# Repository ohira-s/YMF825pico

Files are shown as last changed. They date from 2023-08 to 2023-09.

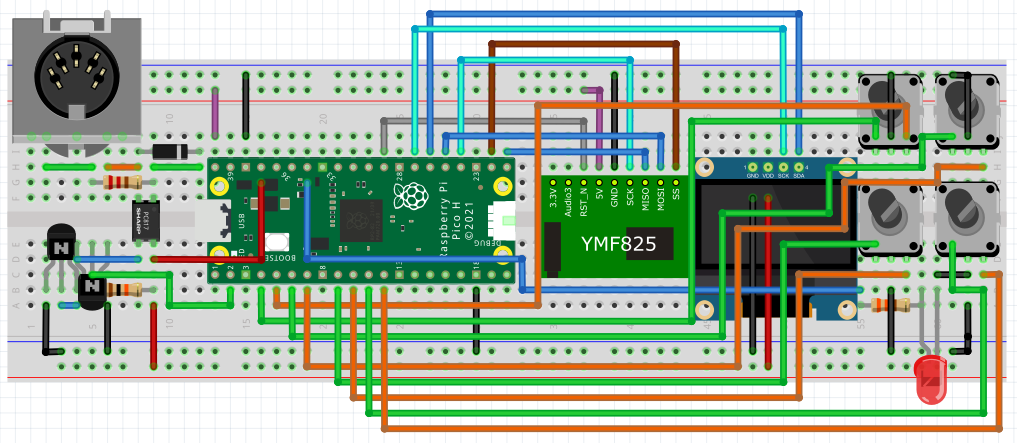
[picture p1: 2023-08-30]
doc/YMF825pico_bread.png

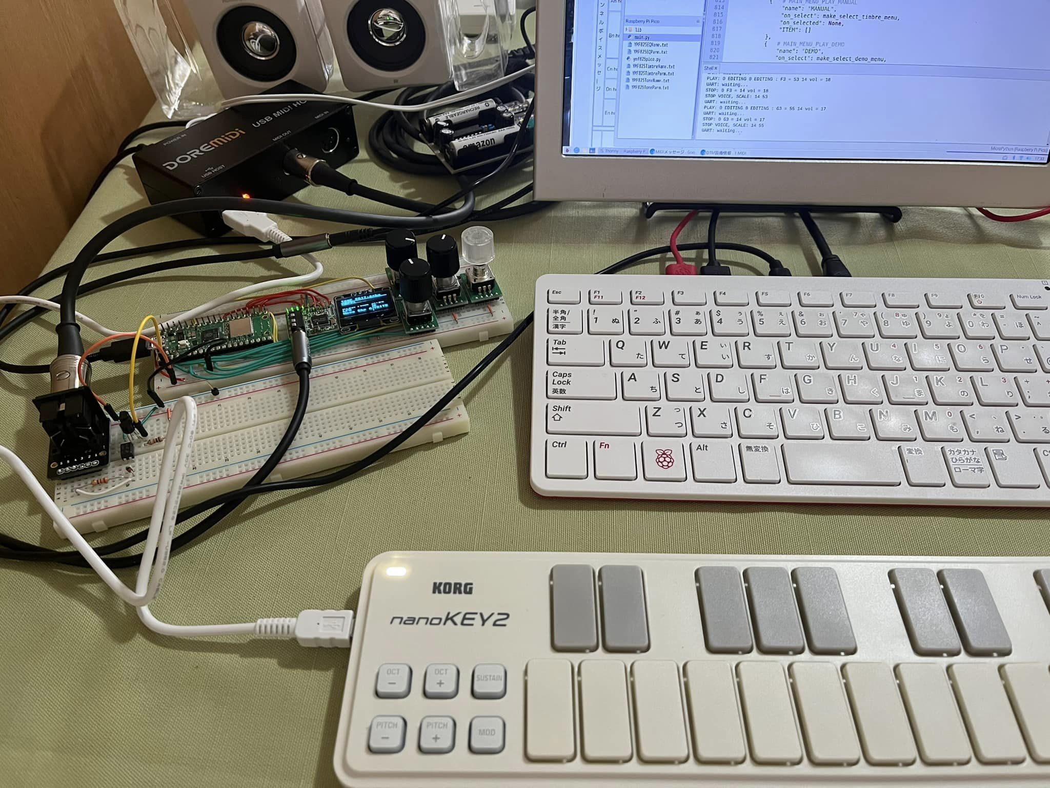
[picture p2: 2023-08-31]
doc/YMF825pico_photo.jpg

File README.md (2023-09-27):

# YMF825pico
YMF825 FM synthesizer controlled with Raspberry Pi PICO.

## Installations:
- Prepare Raspberry Pi PICO or PICO W with micropython.
- Copy all files in data folder into PICO / folder.
- Copy all files in scores folder into PICO /scores/ folder.
- Copy YMF825pico_synth_main.py into PICO as main.py.
- Copy YMF825pico.py into PICO.
- YMF825piBasic.py is a test program, so don't care this file.

## Quick start:
- Connect a MIDI OUT of your MIDI instrument to a MIDI DIN5 connector of YMF825pico.
- MIDI CH should be 1ch.
- Connect a passive speaker or amplifire to a audio output of YMF825 board.
- Turn on PICO.
- Play your MIDI instrument.

## Specifications:
- FM synthesizer with 7 algorithms and 4 operators (A, B, C, D).
- 29 wave forms each operator.
- 16 voices.  Each voice can have different tone.
- Multi Timbre. A timbre consists of 4 portions (0..3) with each tone.
- Each portion in a timbre has a MIDI channel to play with both note on and off.
- 3 layers biquad filters are placed following the sound output. 
- You can save 10 databanks each bank contains 20 Timbre sets, 20 Tones and 10 Equalizers in PICO.

## MIDI Events
- Note on event with verosity.
- Sustain pedal event.
- Pitch+ event increments the Base Tone Number (BTN).
- Pitch- event decrements the Base Tone Number (BTN).
- Modulation event resets the BTN to zero (default).
    Therefore ((MIDI CH - 1 + BTN) % 4) corresponds to a portion number to play.
    YMF825 chip does not support both pitch bend and modulation,
    so YMF825pico assigns the original functions to these events.

## Interfaces
- An OLED display and 4 rotary encoders for UI to control the synthesizer. 
- MIDI IN (DIN5) available (NOT support USB MIDI).
- Audio output for a stereo passive speaker (but output is monoral).
    
## YMF825 Sound Editor:
- [User's Manual](https://github.com/ohira-s/YMF825pico/blob/master/doc/YMF825picoUsersManual.md)
- [Web Site（日本語）](https://www.thymes-square.net/?p=41)

  The web site is written in Japanese, and access to the site might be limited from Japan for security problems.  Sorry for inconvenience.

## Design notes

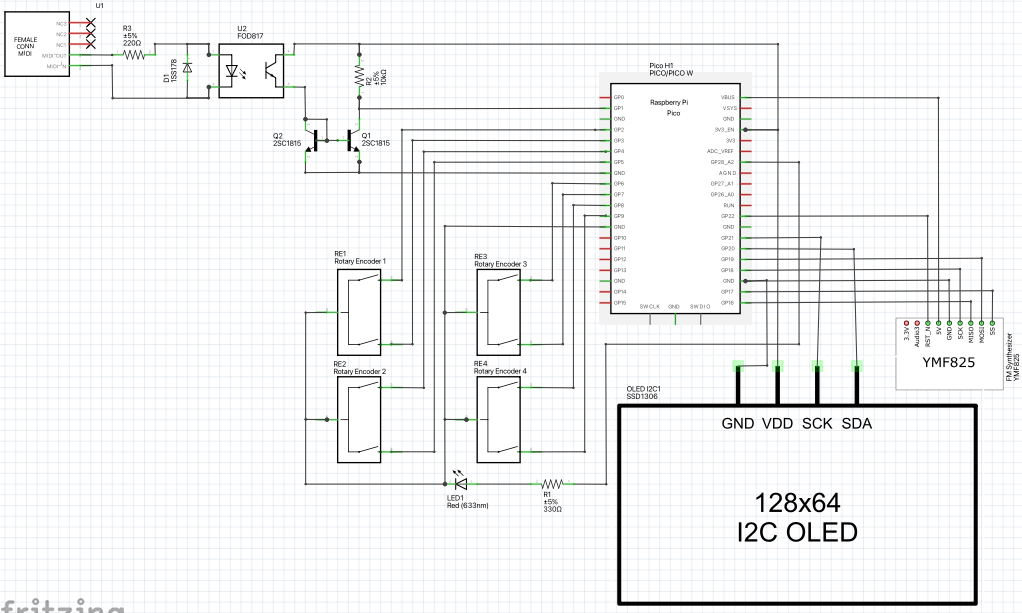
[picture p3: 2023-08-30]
doc/YMF825pico_circuit.png

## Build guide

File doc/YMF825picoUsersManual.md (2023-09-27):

# **YMF825pico User's Manual**
## Sound
- FM synthesizer with 7 algorithms and 4 operators (A, B, C, D).
- 29 wave forms each operator.
- 16 voices.  Each voice can have different tone.
- Multi Timbre. A timbre consists of 4 portions (0..3) with each tone.
- Each portion in a timbre has a MIDI channel to play with both note on and off.
- 3 layers biquad filters are placed following the sound output. 
- You can save 10 databanks each bank contains 20 Timbre sets, 20 Tones and 10 Equalizers in PICO.

    MIDI CHa ---> TIMBREx-PORTION0 ---> DATABANK0..9:TONE0..19 ---> VOICES0..15 / VOLUME0..31

    MIDI CHb ---> TIMBREx-PORTION1 ---> DATABANK0..9:TONE0..19 ---> VOICES0..15 / VOLUME0..31

    MIDI CHc ---> TIMBREx-PORTION2 ---> DATABANK0..9:TONE0..19 ---> VOICES0..15 / VOLUME0..31

    MIDI CHd ---> TIMBREx-PORTION3 ---> DATABANK0..9:TONE0..19 ---> VOICES0..15 / VOLUME0..31

| BLOCK: | DATABANK  | TIMBRE  | PORTION  | MIDI CH | VOICE | DATABANK:TONE  | EQUALIZER  |
|--- | --- | --- | --- | --- | --- | ----- | --- |
| QTY: | 0..9 | 0..19 | 0..3 | 1..16 | 0..15 | 0..19 | 0..9 |
| STRUCTURE: | DATABANKi | TIMBREj | PORTION0 | a  | V0from..V0to | DATABANKt:TONEp | EQUALIZERx |
| | | | PORTION1 | b | V1from..V1to | DATABANKu:TONEq | |
| | | | PORTION2 | c | V2from..V2to | DATABANKv:TONEr | |
| | | | PORTION3 | d | V3from..V3to | DATABANKw:TONEs | |

- You can assign same MIDI channel to any timbre potion.  In this case, all tones with the same MIDI channel will be played at the same time.

## MIDI Controles
- Note on event with MIDI channel and verosity.
- Note off event with MIDI channel.
- Sustain event pedal.
- Pitch+ event increments the Base Tone Number (BTN).
- Pitch- event decrements the Base Tone Number (BTN).
- Modulation event resets the BTN to zero (default).

  Therefore (MIDI Channel + BTN + 1) % 4 corresponds to a portion number to play. YMF825 chip does not support both pitch bend and modulation, so YMF825pico assigns the original functions to these events.

## Interfaces
- An OLED display and 4 rotary encoders for UI to control the synthesizer.
- MIDI IN (DIN5) available (NOT support USB MIDI).
- Audio output for a stereo passive speaker (but output is monoral).
## Softwares
- Interpreter: micropython for Raspberry Pi PICO.
- Application: main.py and ymf825pico.py
## Hardwares
- YMF825 breakout board
- Raspberry Pi PICO or PICO W
- MIDI/UART (3.3v) conversion circuit
- USB MIDI/MIDI interface (if you need)

# **System Block Diagram**
| Hardwares | Pins  | Dir  | PICO Pins |
| --- | ----- | ---- | --- |
| MIDI IN(DIN5)--->UART I/F | Tx | ---> | UART.Rx |
| YMF825 breakout board | RST_N | <--- | GPIO |
| | SS | <--- | GPIO |
| | CLK | <--- | SPI.CLK |
| | MOSI  | <--- | SPI.MOSI |
| | MISO  | ---> | SPI.MISO |
| OLED Display SSD1306 | SCL | <--- | I2C.SCL |
| | SDA | <--- | I2C.SDA |
| Rotary Encoder 1 (RT1:Main) | A | ---> | GPIO.pullup |
| | B | ---> | GPIO.pullup |
| Rotary Encoder 2 (RT2:Category) | A | ---> | GPIO.pullup |
| | B | ---> | GPIO.pullup |
| Rotary Encoder 3 (RT3:Item) | A | ---> | GPIO.pullup |
| | B | ---> | GPIO.pullup |
| Rotary Encoder 4 (RT4:Value) | A | ---> | GPIO.pullup |
| | B | ---> | GPIO.pullup |
| LED (sending data to YMF825) | anode | <--- | GPIO |
| - built-in LED in RT4 | | | |

# **Menu Structures**

YMF825pico has 4 layers menu structures as below.

	⁃ Main
	⁃ Category
	⁃ Item
	⁃ Value

| Main | Category | Item | Value |
| --- | --- | --- | --- |
| PLAY | MANUAL | *timbre list* | NO/SET |
| | EQIALIZER | *equalizer list* | NO/PLAY |
| | DEMO | DEMO1..3 | NO/PLAY |
| | DATABANK | 0..9 | NO/PLAY |
| TIMBRE NAME | *timbre list* | A..z0..9 | =A..z0..9 |
| TIMBRE EDIT | *timbre list* | *parameters* | *values* |
| TONE NAME | *tone list* | A..z0..9 | =A..z0..9 |
| TONE EDIT | *tone list* | *parameters* | *values* |
| TONE COPY | *tone list* | *tone list* | NO/SURE?/YES |
| EQUALIZER NAME | *equalizer list* | A..z0..9 | =A..z0..9 |
| EQUALIZER EDIT | *equalizer list* | *parameters* | *values* |

*italic*: variable list

There are 4 rotary encoders to change each layer's value.  For example, rotary encode 1 (RT1) is for the Main menu.  Rotate RT1, the Main menu will change the value as below.

    PLAY <--> TIMBRE NAME <--> TIMBRE EDIT <--> TONE NAME <-->
    TONE EDIT <--> TONE COPY <--> PLAY.

Turning a rotary encoder right, the menu scrolls down or the value is up. Turning it left, the menu scrolls up or the value is down.

- Rotary Encode and Menu

    | RT1  | RT2      | RT3  | RT4  |
    | ---- | -------- | ---- | ---- |
    | Main | Category | Item | Value|

An OLED display shows you the menus and the values.  THe layout is as below.

- OLED Display Layout

    | Main     |       |
    | -------- | ----- |
    | Category |       |
    | Item     | Value |
    | :        | :     |

- Example: TIMBRE EDIT

    | TIMBRE EDIT |        |
    | ----------- | ------ |
    | ROCK BAND   |        |
    | DATABANK0   | 0      |
    | TONE0       | GUITAR |
    | VOICE L0    | 0      |
    | VOICE H0    | 5      |
    | VOLUME0     | 31     |
    | DATABANK1   | 0      |
    | TONE1       | BASS   |
    | VOICE L1    | 6      |
    | VOICE H1    | 8      |
    | VOLUME1     | 31     |
    | DATABANK2   | 3      |
    | TONE2       | DRUM   |
    | VOICE L2    | 9      |
    | VOICE H2    | 11     |
    | VOLUME2     | 20     |
    | DATABANK3   | 1      |
    | TONE3       | SYNTH  |
    | VOICE L3    | 12     |
    | VOICE H3    | 15     |
    | VOLUME3     | 25     |

# **Main: PLAY**
- ## **Category: MANUAL (PLAY > MANUAL)**
  Play YMF825 by the current timbre, receive MIDI data via MIDI interface (DIN5).

    - ### **Item:** ***timbre list***
        The timbre names are listed in the Item area.

    - #### **Items and Values**
        | Items             | Values | Descriptions |
        | ----------------- | ------ | ------------ |
        | NOTES OFF         | NO     | Nothing happends. |
        |                   | SURE?  | Nothing happends. |
        |                   | YES    | All notes off. |
        | ***timbre name*** | NO     | Nothing happens. |
        |                   | SET    | Play with this timbre. |

- ## **Category: EQUALIZER (PLAY > EQUALIZER)**
  Apply an equalizer to playing sound.

    - ### **Item:** ***timbre list***
        The equalizer names are listed in the Item area.

    - #### **Items and Values**
        | Items                | Values | Descriptions |
        | -------------------- | ------ | ------------ |
        | ***equalizer name*** | NO     | Nothing happends. |
        |                      | SET    | Apply this equalizer. |

- ## **Category: DEMO (PLAY > DEMO)**
  Play demo music by the current timbre.

    - ### **Item:** ***demo list***
        The demo music names are listed in the Item area.
        Demo music must be written in YMF825pico sequencer format.

    - #### **Items and Values**
        | Items           | Values | Descriptions |
        | --------------- | ------ | ------------ |
        | ***demo name*** | NO     | Nothing happens. |
        |                 | PLAY   | Play this demo. |

- ## **Category: DATABANK (PLAY > DATABANK)**
  Load a dataset from a databank.

    - ### **Item:** ***demo list***
        Numbers of the databank (0..9) are listed in the Item area.

    - #### **Items and Values**
        | Items           | Values | Descriptions |
        | --------------- | ------ | ------------ |
        | ***0..9***      | NO     | Nothing happens. |
        |                 | LOAD   | Load this dataset. |

# **Main: TIMBRE NAME**
- ## **Category:** ***timbre list*** (TIMBRE NAME > ***timbre list***)
  Choose a timbre name to edit it.

    - ### **Item:** ***name characters***
        Characters of the timbre name are listed in the Item area.

    - #### **Items and Values**
        | Items           | Values     | Descriptions |
        | --------------- | ---------- | ------------ |
        | ***character*** | =          | Not change. |
        |                 | A..z0..9   | Change the character to this. |
        | SAVE            | NO         | Nothing happens. |
        |                 | SURE?      | Nothing happens. |
        |                 | YES        | Save as new name. |
        | CANCEL          | NO         | Nothing happens. |
        |                 | SURE?      | Nothing happens. |
        |                 | YES        | Cancel the changes. |

# **Main: TIMBRE EDIT**
- ## **Category:** ***timbre list*** (TIMBRE EDIT > ***timbre list***)
  Choose a timbre name to edit the parameters.

    - ### **Item:** ***timbre parameters***
        Timbre parameters are listed in the Item area.  A timbre has 4 tones (0..3).

    - #### **Items and Values**
        | Items           | Values          | Descriptions |
        | --------------- | --------------- | ------------ |
        | DATABANK0       | 0..9            | Select a databank number of the tone0. |
        | TONE0           | ***tone list*** | Select a tone for MIDI channel 1. |
        | VOICE L0        | 0..15           | Lower scale to play with this tone. |
        | VOICE H0        | 0..15           | Upper scale to play with this tone. |
        | VOLUME0         | 0..31           | Tone volume. |
        | MIDI CH0        | 1..16           | MIDI channel. |
        | DATABANK1       | 0..9            | Select a databank number of the tone1. |
        | TONE1           | ***tone list*** | Select a tone for MIDI channel 2. |
        | VOICE L1        | 0..15           | Lower voice number to assign this tone. |
        | VOICE H1        | 0..15           | Upper voice number to assign this tone. |
        | VOLUME1         | 0..31           | Tone volume. |
        | MIDI CH1        | 1..16           | MIDI channel. |
        | DATABANK2       | 0..9            | Select a databank number of the tone2. |
        | TONE2           | ***tone list*** | Select a tone for MIDI channel 3. |
        | VOICE L2        | 0..15           | Lower scale to play with this tone. |
        | VOICE H2        | 0..15           | Upper scale to play with this tone. |
        | VOLUME2         | 0..31           | Tone volume. |
        | MIDI CH2        | 1..16           | MIDI channel. |
        | DATABANK3       | 0..9            | Select a databank number of the tone3. |
        | TONE3           | ***tone list*** | Select a tone for MIDI channel 4. |
        | VOICE L3        | 0..15           | Lower scale to play with this tone. |
        | VOICE H3        | 0..15           | Upper scale to play with this tone. |
        | VOLUME3         | 0..31           | Tone volume. |
        | MIDI CH3        | 1..16           | MIDI channel. |
        | SAVE            | NO              | Nothing happens. |
        |                 | SURE?           | Nothing happens. |
        |                 | YES             | Save as new name. |
        | CANCEL          | NO              | Nothing happens. |
        |                 | SURE?           | Nothing happens. |
        |                 | YES             | Cancel the changes. |
        - Never overlap each tone's ranges of the voice number.
        - VOLUME? value is from 0 to 31.  The value is mapped from 0% to 100% to control master volume of the timbre?.

              The tone volume corresponds to MIDI velosity.

# **Main: TONE NAME**
- ## **Category:** ***tone list*** (TONE NAME > ***tone list***)
  Choose a tone name to edit it.

    - ### **Item:** ***name characters***
        Characters of the tone name are listed in the Item area.

    - #### **Items and Values**
        | Items           | Values     | Descriptions |
        | --------------- | ---------- | ------------ |
        | ***character*** | =          | Not change. |
        |                 | A..z0..9   | Change the character to this. |
        | SAVE            | NO         | Nothing happens. |
        |                 | SURE?      | Nothing happens. |
        |                 | YES        | Save as new name. |
        | CANCEL          | NO         | Nothing happens. |
        |                 | SURE?      | Nothing happens. |
        |                 | YES        | Cancel the changes. |

# **Main: TONE EDIT**
- ## **Category:** ***tone list*** (TONE EDIT > ***tone list***)
  Choose a tone name to edit the tone parameters.

    - ### **Item:** ***name characters***
        Tone parameters are listed in the Item area.
        A demo scores will sound automatically when target item editing is changed and the parameter value was changed.

    - #### **Items and Values**
        | Items           | Values     | Descriptions |
        | --------------- | ---------- | ------------ |
        | Basic OCT       | 0..3       | Basic octave. |
        | Algorithm       | 0..7       | Algorithm. |
        | LFO             | 0..7       | LFO frequency. |
        | Wave Shp A      | 0..31      | Operator-A wave shape. |
        | Total LV A      | 0..31      | Operator-A output level. |
        | MCM Freq A      | 0..15      | Operator-A multi control magnification frequency. |
        | Feedback A      | 0..7       | Operator-A feedback level. |
        | Detune   A      | 0..7       | Operator-A detune. |
        | Atack RT A      | 0..15      | Operator-A attack rate. |
        | Decay RT A      | 0..15      | Operator-A decay rate. |
        | Sustn LV A      | 0..15      | Operator-A sustain level. |
        | Sustn RT A      | 0..15      | Operator-A sustain rate. |
        | Reles RT A      | 0..15      | Operator-A release rate. |
        | Vibrt EN A      | OFF / ON   | Operator-A enable vibrate. |
        | Vibrt DP A      | 0..3       | Operator-A depth of vibrate. |
        | Amp M EN A      | OFF/ ON    | Operator-A enable amp modulation. |
        | Amp M DP A      | 0..3       | Operator-A depth of amp modulation. |
        | Key S EN A      | OFF / ON   | Operator-A key scale sensitivity. |
        | Key S LV A      | 0..3       | Operator-A key scale level sensivitiy. |
        | IgnKy OF A      | OFF / ON   | Operator-A ignore key off. |
        | Wave Shp B      | 0..31      | Operator-B wave shape. |
        | Total LV B      | 0..31      | Operator-B output level. |
        | MCM Freq B      | 0..15      | Operator-B multi control magnification frequency. |
        | Feedback B      | 0..7       | Operator-B feedback level. |
        | Detune   B      | 0..7       | Operator-B detune. |
        | Atack RT B      | 0..15      | Operator-B attack rate. |
        | Decay RT B      | 0..15      | Operator-B decay rate. |
        | Sustn LV B      | 0..15      | Operator-B sustain level. |
        | Sustn RT B      | 0..15      | Operator-B sustain rate. |
        | Reles RT B      | 0..15      | Operator-B release rate. |
        | Vibrt EN B      | OFF / ON   | Operator-B enable vibrate. |
        | Vibrt DP B      | 0..3       | Operator-B depth of vibrate. |
        | Amp M EN B      | OFF/ ON    | Operator-B enable amp modulation. |
        | Amp M DP B      | 0..3       | Operator-B depth of amp modulation. |
        | Key S EN B      | OFF / ON   | Operator-B key scale sensitivity. |
        | Key S LV B      | 0..3       | Operator-B key scale level sensivitiy. |
        | IgnKy OF B      | OFF / ON   | Operator-B ignore key off. |
        | Wave Shp C      | 0..31      | Operator-C wave shape. |
        | Total LV C      | 0..31      | Operator-C output level. |
        | MCM Freq C      | 0..15      | Operator-C multi control magnification frequency. |
        | Feedback C      | 0..7       | Operator-C feedback level. |
        | Detune   C      | 0..7       | Operator-C detune. |
        | Atack RT C      | 0..15      | Operator-C attack rate. |
        | Decay RT C      | 0..15      | Operator-C decay rate. |
        | Sustn LV C      | 0..15      | Operator-C sustain level. |
        | Sustn RT C      | 0..15      | Operator-C sustain rate. |
        | Reles RT C      | 0..15      | Operator-C release rate. |
        | Vibrt EN C      | OFF / ON   | Operator-C enable vibrate. |
        | Vibrt DP C      | 0..3       | Operator-C depth of vibrate. |
        | Amp M EN C      | OFF/ ON    | Operator-C enable amp modulation. |
        | Amp M DP C      | 0..3       | Operator-C depth of amp modulation. |
        | Key S EN C      | OFF / ON   | Operator-C key scale sensitivity. |
        | Key S LV C      | 0..3       | Operator-C key scale level sensivitiy. |
        | IgnKy OF C      | OFF / ON   | Operator-C ignore key off. |
        | Wave Shp D      | 0..31      | Operator-D wave shape. |
        | Total LV D      | 0..31      | Operator-D output level. |
        | MCM Freq D      | 0..15      | Operator-D multi control magnification frequency. |
        | Feedback D      | 0..7       | Operator-D feedback level. |
        | Detune   D      | 0..7       | Operator-D detune. |
        | Atack RT D      | 0..15      | Operator-D attack rate. |
        | Decay RT D      | 0..15      | Operator-D decay rate. |
        | Sustn LV D      | 0..15      | Operator-D sustain level. |
        | Sustn RT D      | 0..15      | Operator-D sustain rate. |
        | Reles RT D      | 0..15      | Operator-D release rate. |
        | Vibrt EN D      | OFF / ON   | Operator-D enable vibrate. |
        | Vibrt DP D      | 0..3       | Operator-D depth of vibrate. |
        | Amp M EN D      | OFF/ ON    | Operator-D enable amp modulation. |
        | Amp M DP D      | 0..3       | Operator-D depth of amp modulation. |
        | Key S EN D      | OFF / ON   | Operator-D key scale sensitivity. |
        | Key S LV D      | 0..3       | Operator-D key scale level sensivitiy. |
        | IgnKy OF D      | OFF / ON   | Operator-D ignore key off. |
        | CPadsl A>B      | NO         | Nothing happens. |
        |                 | SURE?      | Nothing happens. |
        |                 | YES        | Copy ADSSL-A to B. |
        | CPadsl A>C      | NO         | Nothing happens. |
        |                 | SURE?      | Nothing happens. |
        |                 | YES        | Copy ADSSL-A to C. |
        | CPadsl A>D      | NO         | Nothing happens. |
        |                 | SURE?      | Nothing happens. |
        |                 | YES        | Copy ADSSL-A to D. |
        | CPadsl B>A      | NO         | Nothing happens. |
        |                 | SURE?      | Nothing happens. |
        |                 | YES        | Copy ADSSL-B to A. |
        | CPadsl B>C      | NO         | Nothing happens. |
        |                 | SURE?      | Nothing happens. |
        |                 | YES        | Copy ADSSL-B to C. |
        | CPadsl B>D      | NO         | Nothing happens. |
        |                 | SURE?      | Nothing happens. |
        |                 | YES        | Copy ADSSL-B to D. |
        | CPadsl C>A      | NO         | Nothing happens. |
        |                 | SURE?      | Nothing happens. |
        |                 | YES        | Copy ADSSL-C to A. |
        | CPadsl C>B      | NO         | Nothing happens. |
        |                 | SURE?      | Nothing happens. |
        |                 | YES        | Copy ADSSL-C to B. |
        | CPadsl C>D      | NO         | Nothing happens. |
        |                 | SURE?      | Nothing happens. |
        |                 | YES        | Copy ADSSL-C to D. |
        | CPadsl D>A      | NO         | Nothing happens. |
        |                 | SURE?      | Nothing happens. |
        |                 | YES        | Copy ADSSL-D to A. |
        | CPadsl D>B      | NO         | Nothing happens. |
        |                 | SURE?      | Nothing happens. |
        |                 | YES        | Copy ADSSL-D to B. |
        | CPadsl D>C      | NO         | Nothing happens. |
        |                 | SURE?      | Nothing happens. |
        |                 | YES        | Copy ADSSL-D to C. |
        | SAVE            | NO         | Nothing happens. |
        |                 | SURE?      | Nothing happens. |
        |                 | YES        | Save the changes to PICO. |
        | CANCEL          | NO         | Nothing happens. |
        |                 | SURE?      | Nothing happens. |
        |                 | YES        | Cancel the changes. |
        - You will see an expression like "Ab+cd" as the algorithm parameter.

          - a, b, c, d mean an operator in YMF825.
          - A capital letter like 'A' means an operator with self-feedback.
          - A small letter like 'a' means an operator without self-feedback.
          - '+' means a mixer.
          - Ab means the operator-A modulates the operator-b. 

        - If you choose Wave Shape, Total Level and MCM Frequency, you will see a 4 sub panes editor.  You can change these parameters in the same display.
        - If you choose ADSSL, you will see a 4 sub panes editor.  You can change these parameters in the same display.

# **Main: TONE COPY**
- ## **Category:** ***tone list*** (TONE COPY > ***tone list***)
  Choose a tone name to copy to another tone.

    - ### **Item:** DATABANK
        Choose a databank number (0..9) to copy a tone data to.  The tone list will be re-loaded just after the databank is changed.

    - ### **Item:** ***tone list***
        Tone names are listed in the Item area.  The tone data of category tone name will be copied to an item tone name.

    - #### **Items and Values**
        | Items           | Values| Descriptions |
        | --------------- | ----- | ------------ |
        | DATABANK        | 0..9  | Choose a databank to copy to |
        | ***tone list*** | NO    | Nothing happens. |
        |                 | SURE? | Nothing happens. |
        |                 | YES   | Copy to this tone. |

# **Main: EQUALIZER NAME**
- ## **Category:** ***equalizer list*** (EQUALIZER NAME > ***timbre list***)
  Choose a timbre name to edit it.

    - ### **Item:** ***name characters***
        Characters of the equalizer name are listed in the Item area.

    - #### **Items and Values**
        | Items           | Values     | Descriptions |
        | --------------- | ---------- | ------------ |
        | ***character*** | =          | Not change. |
        |                 | A..z0..9   | Change the character to this. |
        | SAVE            | NO         | Nothing happens. |
        |                 | SURE?      | Nothing happens. |
        |                 | YES        | Save as new name. |
        | CANCEL          | NO         | Nothing happens. |
        |                 | SURE?      | Nothing happens. |
        |                 | YES        | Cancel the changes. |

# **Main: EQUALIZER EDIT**
- ## **Category:** ***equalizer list*** (EQUALIZER EDIT > ***equalizer list***)
  Choose a equalizer name to edit the parameters.

    - ### **Item:** ***equalizer parameters***
        Equalizer parameters are listed in the Item area.  An equalizer has 3 biquad filters (1..3).

    - #### **Items and Values**
        | Items           | Values          | Descriptions |
        | ------------ | --------------- | ------------ |
        | DECIMAL PLC  | 0..9            | Choose a decimal place to edit. 0 means the integer part. |
        | FLT Type     | DIRECT          | Use parameters directly. |
        |              | LPF:FcQ         | Calculate parameters for LPF. |
        |              | HPF:FcQ         | Calculate parameters for HPF. |
        |              | BPFskt:FcQ      | Calculate parameters for BPFskt. |
        |              | BPF0db:FcQ      | Calculate parameters for BPF0db. |
        |              | NOTCH:FcQ       | Calculate parameters for NOTCH. |
        |              | APF:FcQ         | Calculate parameters for APF. |
        | Calc FLT     | NO              | Nothing happens. |
        |              | SURE?           | Nothing happens. |
        |              | CALC            | Calculate filter parameters. |
        | EQ1 B0/Fc    | -2.0 .. 2.0     | 1st biquad filter parameter b0. |
        |              |  0.0 .. 48.0    | 1st cut off frequency Fc1(kHz). |
        | EQ1 B1/Qv    | -2.0 .. 2.0     | 1st biquad filter parameter b1. |
        |              |  0.0 .. 10.0    | 1st Q value Qv1. |
        | EQ1 B2       | -2.0 .. 2.0     | 1st biquad filter parameter b2. |
        | EQ1 A1       | -2.0 .. 2.0     | 1st biquad filter parameter a1. |
        | EQ1 A2       | -2.0 .. 2.0     | 1st biquad filter parameter a2. |
        | FLT Type     | DIRECT          | Use parameters directly. |
        |              | LPF:FcQ         | Calculate parameters for LPF. |
        |              | HPF:FcQ         | Calculate parameters for HPF. |
        |              | BPFskt:FcQ      | Calculate parameters for BPFskt. |
        |              | BPF0db:FcQ      | Calculate parameters for BPF0db. |
        |              | NOTCH:FcQ       | Calculate parameters for NOTCH. |
        |              | APF:FcQ         | Calculate parameters for APF. |
        | Calc FLT     | NO              | Nothing happens. |
        |              | SURE?           | Nothing happens. |
        |              | CALC            | Calculate filter parameters. |
        | EQ2 B0/Fc    | -2.0 .. 2.0     | 2nd biquad filter parameter b0. |
        |              |  0.0 .. 48.0    | 1st cut off frequency Fc2(kHz). |
        | EQ2 B1/Qv    | -2.0 .. 2.0     | 2nd biquad filter parameter b1. |
        |              |  0.0 .. 10.0    | 1st Q value Qv2. |
        | EQ2 B2       | -2.0 .. 2.0     | 2nd biquad filter parameter b2. |
        | EQ2 A1       | -2.0 .. 2.0     | 2nd biquad filter parameter a1. |
        | EQ2 A2       | -2.0 .. 2.0     | 2nd biquad filter parameter a2. |
        | FLT Type     | DIRECT          | Use parameters directly. |
        |              | LPF:FcQ         | Calculate parameters for LPF. |
        |              | HPF:FcQ         | Calculate parameters for HPF. |
        |              | BPFskt:FcQ      | Calculate parameters for BPFskt. |
        |              | BPF0db:FcQ      | Calculate parameters for BPF0db. |
        |              | NOTCH:FcQ       | Calculate parameters for NOTCH. |
        |              | APF:FcQ         | Calculate parameters for APF. |
        | Calc FLT     | NO              | Nothing happens. |
        |              | SURE?           | Nothing happens. |
        |              | CALC            | Calculate filter parameters. |
        | EQ3 B0/Fc    | -2.0 .. 2.0     | 3rd biquad filter parameter b0. |
        |              |  0.0 .. 48.0    | 1st cut off frequency Fc3(kHz). |
        | EQ3 B1/Qv    | -2.0 .. 2.0     | 3rd biquad filter parameter b1. |
        |              |  0.0 .. 10.0    | 1st Q value Qv3. |
        | EQ3 B2       | -2.0 .. 2.0     | 3rd biquad filter parameter b2. |
        | EQ3 A1       | -2.0 .. 2.0     | 3rd biquad filter parameter a1. |
        | EQ3 A2       | -2.0 .. 2.0     | 3rd biquad filter parameter a2. |
        | LISTEN       | NO              | Nothing happens. |
        |              | PLAY            | Play a sample sound with the current equalizer settings. |
        | SAVE         | NO              | Nothing happens. |
        |              | SURE?           | Nothing happens. |
        |              | YES             | Save as new name. |
        | CANCEL       | NO              | Nothing happenSs. |
        |              | SURE?           | Nothing happens. |
        |              | YES             | Cancel the changes. |
        | RESET        | NO              | Nothing happens. |
        |              | SURE?           | Nothing happens. |
        |              | YES             | Reset to the all pass filter. |
        - A biquad filter's equation is as below.

                  b0 + b1/z + b2/z/z

          H(z) = -----------------------

                  a0 + a1/z + a2/z/z        : a0-->0.0

        - If FLT Type is DIRECT, parameter values B0, B1, B2, A1, A2 are used as filter parameters directly.
        - If a filter name is selected as FLT Type, you should set a cut off frequency (kHz) into a B0/Fc, and a Q value into a B1/Qv.  Then selecting CALC in the Calc FLT, the filter parameters are calculated in the B0, B1, B2, A1, A2 rows.

# **Music Sequencer File Format**
YMF825pico can play music with sequencer file. The file format is the original for YMF825pico.

## Header
The header part declares a databank and a timbre for an instruments to play sequencer music. And also declares an interval time to play one sequence step. 
### Format
    
    #DATABANK=***databank number***
    #TIMBRE=***timbre number***
    #WAIT=***interval(sec)***

### Example
    
    #DATABANK=1
    #TIMBRE=5
    #WAIT=0.5

## Score
The score line defines scores for each timbre portion.
### Format

    |***portion number***:***start note name***:***any characters for score***|***portion number***:...|

### Example
    |0:C3:_*_*__*_*_*__*_*__*_*_*__|1:F2:_*_*__*_*_|2:C4:_*_*__*_*_*__|

The score for the portion 0 covers the notes from C3 to C5. '_' means a white key in piano and '*' means a black key. However you can use any character except '|' for '_' and '*'.

In this case, the portion 3 has no note to play.

## Notes
### Format
    
    volume(0..9)  
    note off(-)

### Example

    |0:C3:_*_*__*_*_*__*_*__*_*_*__|1:F2:_*_*_*__*_*_|2:C4:_*_*__*_*_*__|
          9                                6    6
          .                                .    .
          .   7                            - 6  -   6   
          -   .                              .      .
              .  5                         6 -  6   -
              -  .                         .    .
                 .                         .    .
                 -                         -    -
    |0:C3:_*_*__*_*_*__*_*__*_*_*__|1:F2:_*_*__*_*_|2:C4:_*_*__*_*_*__|
          9   9  9                                       8   8      7
          .   .  .                                       .   .      .
          9   9  9                                       -   -      -
          .   .  .                                       8   8      7
          -   -  -                                       -   -      -

In the portion 0, YMF825pico sequencer plays C3 at the step 1.  C3 cotinues 3 steps, then stop at step 4.

In the portion2, both G2 and C3 sound at the step 1.

You can write the score line anywhere for getting readable score.

'-' executes a note off.  It uses one step for note off, so no note plays in the step.  If you want to execute note off and note on in one step, write a volume number at the step. '-' executes note off only, but volume number executes note off and note on in a step.

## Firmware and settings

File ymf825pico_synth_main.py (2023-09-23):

#############################################################################
# YMF825 synthesizer with Raspberry Pi PICO W.
#
# Hardware Information:
#   YMF825 bottom view
#     1 2 3 4 5 6 7 8 9
#    -+-+-+-+-+-+-+-+-+-
#   | S M M C G V R     |
#   | S O I L N C S     |
#   |   S S K D C T     |
#   |   I O             |
#   |             Audio Jack
#    ---------------+---
#                   |
#                    ---Amp
#
#   PICO GPIO(pin)      YMF825 name(pin)    LED(n/a)
#     5V          (40)    VCC        (6)
#     GND         (38)    GND        (5)
#     SPI1 MOSI 19(25)    SPI MOSI   (2)
#     SPI1 MISO 16(21)    SPI MISO   (3)
#     SPI1 CLK  18(24)    SPI CLK    (4)
#     SPI1 CS   17(22)    SS         (1)
#     RESET     22(29)    RESET      (7)
#n/a  LED       28(34)                      Anode---1K--->|---Cathode---GND
#
#   PICO GPIO(pin)      SSD1306 name(pin)    LED(n/a)
#     I2C0 SDA  20(24)    SDA        (4)
#     I2C0 SCL  21(25)    SCL        (3)
#                         GND        (2)
#                         VCC(3.3V)  (1)
#
# Copyright (c) by Shunsuke Ohira
#   00.100 2023/08/05: Play Do-Re-Mi
#   01.000 2023/08/31: UI Editor and MIDI Keyboard are available.
#   01.001 2023/09/04: Databank available
#   01.100 2023/09/06: Sequencer available
#   01.200 2023/09/08: Equalizer available
#   01.210 2023/09/12: GUI for operator volumes and ADSSR
#   01.211 2023/09/13: GUI for Algorithm
#   01.212 2023/09/19: Reduce global variable memory
#   01.300 2023/09/19: Tones in the timbre can be selected from the other databank
#   01.400 2023/09/21: Bi quad filter parameters calculation (LPF, HPF, BPFskt, BPF0db, NOTCH, APF, PEAK)
#   01.500 2023/09/21: MIDI channel can be assigned to each timbre portion
#   01.501 2023/09/22: Ignore Realtime Clock (0xF8) and Active Sensing (0xFE) in MIDI message (too much!!)
#   01.502 2023/09/23: Waiting for receiving parfect MIDI messages via UART to never lost MIDI message
#############################################################################

from ymf825pico import ymf825pico_class
from machine import Pin, I2C, SPI, UART
import ssd1306
import time, os, json, math
import gc

# UART test
UART_CH = 0
UART_TX = 0   # GPIO No.
UART_RX = 1   # GPIO No.
#UART_BAUDRATE = 9600
UART_BAUDRATE = 31250      # MIDI speed

# I2C for SSD1306 OLED Display
I2C_SSD1306_CH = 0
I2C_SSD1306_SDA = 20    # Pin24
I2C_SSD1306_SCL = 21    # Pin25

# SSD1306 OLED Display
DISPLAY_WIDTH = 128
DISPLAY_HEIGHT = 64
DISPLAT_HALF_WIDTH = int(DISPLAY_WIDTH / 2)
DISPLAT_QUOT_WIDTH = int(DISPLAY_WIDTH / 4)
DISPLAY_DIVIDE = 83
DISPLAY_LINE_HEIGHT = 10
DISPLAY_MENU_LINES= 4
display = None

# I2C for SSD1306 OLED Display
i2c_ssd1306 = I2C(I2C_SSD1306_CH, sda=Pin(I2C_SSD1306_SDA), scl=Pin(I2C_SSD1306_SCL))

# Rotary encoders
ROTARY_ENCODERS = [
    # No.     GPIO No.                Pin objects                 Previous pin values       Pjn values             Pin No.
    {"NO": 0, "A_PIN": 2, "B_PIN": 3, "A_SW": None, "B_SW": None, "A_PREV": 2, "B_PREV": 2, "VALUES": [0,0,0,0]},  # Pin 4,  5
    {"NO": 1, "A_PIN": 4, "B_PIN": 5, "A_SW": None, "B_SW": None, "A_PREV": 2, "B_PREV": 2, "VALUES": [0,0,0,0]},  # Pin 6,  7
    {"NO": 2, "A_PIN": 6, "B_PIN": 7, "A_SW": None, "B_SW": None, "A_PREV": 2, "B_PREV": 2, "VALUES": [0,0,0,0]},  # Pin 9, 10
    {"NO": 3, "A_PIN": 8, "B_PIN": 9, "A_SW": None, "B_SW": None, "A_PREV": 2, "B_PREV": 2, "VALUES": [0,0,0,0]}   # Pin11, 12
]

# Timbre portion's volumes10/2go,10/3event,10/4back
timbre_volumes = [1.0] * 4

# YMF825 parameters mapping and order (ABBR, REAL KEY NAME, VALUE RANGE)
PARM_TEXT_OFF_ON = ["OFF", "ON"]
PARM_TEXT_ALGO = ["Ab", "A+b", "A+b+C+d", "(A+bc)d", "Abcd", "Ab+Cd", "A+bcd", "A+bc+d"]
PARM_TEXT_WAVE = [
    "SIN",     "plusSIN", "asbSIN",  "SAIL*2",
    "SIN2x",   "absSN2x", "SQUARE",  "RIBBON",
    "SINcomp", "plusScp", "absScmp", "SAILcmp",
    "SIN2xCp", "plsS2cp", "plusSQR", "-------",
    "TRIANGL", "plusTRI", "absTRIA", "absTRIh",
    "TRIAN2x", "plsTR2x", "plsSQR2", "-----",
    "SAW",     "plusSAW", "absSAW",  "absSAWc",
    "SAW2x",   "absSAW2", "SQUAR/4", "-------"
]
YMF825_PARM = [
    # GENERAL
    ("Basic OCT", "Basic Oct", 4, None),
    ("Algorithm", "Algorithm", 8, PARM_TEXT_ALGO),
    ("LFO", "LFO", 8, None),
    # OP1
    ("Wave Shp A", "Wave Shape1", 32, PARM_TEXT_WAVE),
    ("Total LV A", "Operator Lv1", 32, None),
    ("MCM Freq A", "MCMFreq1", 16, None),
    ("Feedback A", "Feedback Lv1", 8, None),
    ("Detune   A", "Detune1", 8, None),
    ("Atack RT A", "Attack R1", 16, None),
    ("Decay RT A", "Decay R1", 16, None),
    ("Sustn LV A", "Sus Level1", 16, None),
    ("Sustn RT A", "Sus R1", 16, None),
    ("Reles RT A", "Release R1", 16, None),
    ("Vibrt EN A", "Enable Vib1", 2, PARM_TEXT_OFF_ON),
    ("Vibrt DP A", "Depth Vib1", 4, None),
    ("Amp M EN A", "Enable Amp Mod1", 2, PARM_TEXT_OFF_ON),
    ("Amp M DP A", "Depth Amp Mod1", 4, None),
    ("Key S EN A", "KeySc Sens1", 2, PARM_TEXT_OFF_ON),
    ("Key S LV A", "KSL Sens1", 4, None),
    ("IgnKy OF A", "Ign Key Off1", 2, PARM_TEXT_OFF_ON),
    # OP2
    ("Wave Shp B", "Wave Shape2", 32, PARM_TEXT_WAVE),
    ("Total LV B", "Operator Lv2", 32, None),
    ("MCM Freq B", "MCMFreq2", 16, None),
    ("Feedback B", "Feedback Lv2", 8, None),
    ("Detune   B", "Detune2", 8, None),
    ("Atack RT B", "Attack R2", 16, None),
    ("Decay RT B", "Decay R2", 16, None),
    ("Sustn LV B", "Sus Level2", 16, None),
    ("Sustn RT B", "Sus R2", 16, None),
    ("Reles RT B", "Release R2", 16, None),
    ("Vibrt EN B", "Enable Vib2", 2, PARM_TEXT_OFF_ON),
    ("Vibrt DP B", "Depth Vib2", 4, None),
    ("Amp M EN B", "Enable Amp Mod2", 2, PARM_TEXT_OFF_ON),
    ("Amp M DP B", "Depth Amp Mod2", 4, None),
    ("Key S EN B", "KeySc Sens2", 2, PARM_TEXT_OFF_ON),
    ("Key S LV B", "KSL Sens2", 4, None),
    ("IgnKy OF B", "Ign Key Off2", 2, PARM_TEXT_OFF_ON),
    # OP3
    ("Wave Shp C", "Wave Shape3", 32, PARM_TEXT_WAVE),
    ("Total LV C", "Operator Lv3", 32, None),
    ("MCM Freq C", "MCMFreq3", 16, None),
    ("Feedback C", "Feedback Lv3", 8, None),
    ("Detune   C", "Detune3", 8, None),
    ("Atack RT C", "Attack R3", 16, None),
    ("Decay RT C", "Decay R3", 16, None),
    ("Sustn LV C", "Sus Level3", 16, None),
    ("Sustn RT C", "Sus R3", 16, None),
    ("Reles RT C", "Release R3", 16, None),
    ("Vibrt EN C", "Enable Vib3", 2, PARM_TEXT_OFF_ON),
    ("Vibrt DP C", "Depth Vib3", 4, None),
    ("Amp M EN C", "Enable Amp Mod3", 2, PARM_TEXT_OFF_ON),
    ("Amp M DP C", "Depth Amp Mod3", 4, None),
    ("Key S EN C", "KeySc Sens3", 2, PARM_TEXT_OFF_ON),
    ("Key S LV C", "KSL Sens3", 4, None),
    ("IgnKy OF C", "Ign Key Off3", 2, PARM_TEXT_OFF_ON),
    # OP4
    ("Wave Shp D", "Wave Shape4", 32, PARM_TEXT_WAVE),
    ("Total LV D", "Operator Lv4", 32, None),
    ("MCM Freq D", "MCMFreq4", 16, None),
    ("Feedback D", "Feedback Lv4", 8, None),
    ("Detune   D", "Detune4", 8, None),
    ("Atack RT D", "Attack R4", 16, None),
    ("Decay RT D", "Decay R4", 16, None),
    ("Sustn LV D", "Sus Level4", 16, None),
    ("Sustn RT D", "Sus R4", 16, None),
    ("Reles RT D", "Release R4", 16, None),
    ("Vibrt EN D", "Enable Vib4", 2, PARM_TEXT_OFF_ON),
    ("Vibrt DP D", "Depth Vib4", 4, None),
    ("Amp M EN D", "Enable Amp Mod4", 2, PARM_TEXT_OFF_ON),
    ("Amp M DP D", "Depth Amp Mod4", 4, None),
    ("Key S EN D", "KeySc Sens4", 2, PARM_TEXT_OFF_ON),
    ("Key S LV D", "KSL Sens4", 4, None),
    ("IgnKy OF D", "Ign Key Off4", 2, PARM_TEXT_OFF_ON),
]

# Character list
CHARS_LIST= ["="]   # No change
CHARS_LIST += [chr(ch) for ch in list(range(0x41,0x5b))]
#CHARS_LIST += [chr(ch) for ch in list(range(0x61,0x7b))]
CHARS_LIST += [chr(ch) for ch in list(range(0x30,0x3a))]
CHARS_LIST += [" "]

# YMF825pico menu
menu_main = 0
menu_category = 0
menu_item = 0
menu_value = 0
gui_item_menu = None
gui_item_menu_exit = None

#--- YMF825pico menu definitions
# MAIN:PLAY
MAIN_MENU_PLAY = 0

# PLAY>CATEGORY
MAIN_MENU_PLAY_MANUAL = 0
MAIN_MENU_PLAY_EQUALIZER = 1
MAIN_MENU_PLAY_DEMO = 2
MAIN_MENU_PLAY_DATABANK = 3

# MAIN:TIMBRE NAME
MAIN_MENU_TIMBRE_NAME = 1
TIMBRE_NAME_LENGTH = 10

# MAIN:TIMBRE EDIT
MAIN_MENU_TIMBRE_EDIT = 2

# MAIN:TONE NAME
MAIN_MENU_TONE_NAME = 3
TONE_NAME_LENGTH = 10

# MAIN:TONE EDIT
MAIN_MENU_TONE_EDIT = 4

# MAIN:TONE COPY
MAIN_MENU_TONE_COPY = 5

# MAIN:EQUALIZER NAME
MAIN_MENU_EQUALIZER_NAME = 6
EQUALIZER_NAME_LENGTH = 10

# MAIN:EQUALIZER EDIT
MAIN_MENU_EQUALIZER_EDIT = 7


# Edit the tone volume related parameters with GUI
def gui_tone_edit_volumes(gui):
    global menu_main, menu_category, menu_item, menu_value
    global gui_item_menu
    
#    print("GUI EDITOR: TONE VOLUMES:", menu_item, gui)
    gui_item_menu = gui["items"]
    for ui in list(range(len(gui_item_menu))):  
        # Show the current editing VALUE
        i = gui["items"][ui]
        if i == menu_item:
#            print("main, category, item, value=", menu_main, menu_category, i, menu_value)
            value_name = SYNTH_MENU[menu_main]["CATEGORY"][menu_category]["ITEM"][i]["VALUE"][menu_value]["name"]
        # Show the selected VALUE
        else:
            selected = int(SYNTH_MENU[menu_main]["CATEGORY"][menu_category]["ITEM"][i]["selected"])
#            print("MENU:", menu_main, menu_category, i, selected)
            value_name = SYNTH_MENU[menu_main]["CATEGORY"][menu_category]["ITEM"][i]["VALUE"][selected]["name"]

#        print("SHOW=", value_name)
        disp = gui["disp"][ui]
        display.text(disp[0], disp[1], disp[2], True)
        display.text(value_name[:6], disp[1] + 16, disp[2], True)
        if i == menu_item:
            display.hline(disp[1], disp[2] + DISPLAY_LINE_HEIGHT - 2, DISPLAT_QUOT_WIDTH, True)

    display.vline(DISPLAT_HALF_WIDTH, DISPLAY_LINE_HEIGHT * 2 - 2, DISPLAY_HEIGHT - (DISPLAY_LINE_HEIGHT * 2 - 2), True)
    display.hline(0, DISPLAY_LINE_HEIGHT * 4 + 1, DISPLAY_WIDTH, True)


# Edit the tone ADSSL parameters with GUI
def gui_tone_edit_adssls(gui):
    global menu_main, menu_category, menu_item, menu_value
    global gui_item_menu
    
#    print("GUI EDITOR: TONE ADSSLs:", menu_item, gui)
    gui_item_menu = gui["items"]
    parmstr = ["AT", "DC", "SL", "SR", "RR"]
    px = [0, 0, 0, 0, 0]
    py = [0, 0, 0, 0, 0]
    for ui in list(range(len(gui_item_menu))):  
        base = int(ui / 5)
        offset = ui % 5

        # Show the current editing VALUE
        i = gui["items"][ui]
        if i == menu_item:
#            print("main, category, item, value=", menu_main, menu_category, i, menu_value)
            value_parm = menu_value
        # Show the selected VALUE
        else:
            value_parm = int(SYNTH_MENU[menu_main]["CATEGORY"][menu_category]["ITEM"][i]["selected"])
#            print("MENU:", menu_main, menu_category, i, value_parm)

#        print("SHOW=", value_parm, "OP=", base)
        base_x = (0 if base % 2 == 0 else DISPLAT_HALF_WIDTH + 2) + 25
        base_y = DISPLAY_LINE_HEIGHT * (4 + (2 if base >= 2 else 0)) + (1 if base >= 2 else -1)

        # Attack
        if offset == 0:
#            print("AT=", value_parm)
            px[1] = (15 - value_parm) / 15.0
            py[1] = 1.0
        # Decay
        elif offset == 1:
#            print("DC=", value_parm)
            px[2] = (15 - value_parm) / 15.0
        # Sustine level
        elif offset == 2:
#            print("SL=", value_parm)
            py[2] = py[1] - value_parm / 15.0
        # Sustain rate
        elif offset == 3:
#            print("SR=", value_parm)
            px[3] = 1.0
            py[3] = py[2] * (15 - value_parm) / 30.0
        elif offset == 4:
#            print("RR=", value_parm)
            px[4] = (15 - value_parm) / 15.0
            py[4] = py[3] if value_parm == 0 else 0
            x0 = 0
            y0 = 0
            for p in list(range(1,5)):
                x1 = x0 + px[p]
                y1 = py[p]
#                print("LINE:",x0, y0, x1, y1)
                display.line(int(x0 * 8) + base_x, base_y - int(y0 * (DISPLAY_LINE_HEIGHT-1)*2), int(x1 * 8) + base_x, base_y - int(y1 * (DISPLAY_LINE_HEIGHT-1)*2), True)
                x0 = x1
                y0 = y1

        disp = [chr(0x41+base)+parmstr[offset], 0 if base % 2 == 0 else DISPLAT_HALF_WIDTH+2, DISPLAY_LINE_HEIGHT*2 if base <= 1 else DISPLAY_LINE_HEIGHT*4+4]
        if i == menu_item:
            display.text(disp[0], disp[1], disp[2], True)
            display.text(str(value_parm), disp[1], disp[2] + DISPLAY_LINE_HEIGHT, True)
            display.hline(disp[1], disp[2] + DISPLAY_LINE_HEIGHT * 2 - 2, int(DISPLAT_QUOT_WIDTH / 2), True)

    display.vline(DISPLAT_HALF_WIDTH, DISPLAY_LINE_HEIGHT * 2 - 2, DISPLAY_HEIGHT - (DISPLAY_LINE_HEIGHT * 2 - 2), True)
    display.hline(0, DISPLAY_LINE_HEIGHT * 4 + 1, DISPLAY_WIDTH, True)


# Edit the tone Algorithm parameters with GUI
def gui_tone_edit_algorithm(gui):
    global menu_main, menu_category, menu_item, menu_value
    global gui_item_menu

    if menu_item == 1:
        value_parm = menu_value
    # Show the selected VALUE
    else:
        value_parm = int(SYNTH_MENU[menu_main]["CATEGORY"][menu_category]["ITEM"][i]["selected"])

    display.text("Algorithm:{}".format(value_parm), 0, DISPLAY_LINE_HEIGHT * 2, True)
    if value_parm == 0:
        display.text("A--b-->", 20, DISPLAY_LINE_HEIGHT * 4, True)
    elif value_parm == 1:
        display.text("A--", 20, DISPLAY_LINE_HEIGHT * 3, True)
        display.text("   +-->", 20, DISPLAY_LINE_HEIGHT * 4, True)
        display.text("b--", 20, DISPLAY_LINE_HEIGHT * 5, True)
    elif value_parm == 2:
        display.text("A--+-->", 20, DISPLAY_LINE_HEIGHT * 3, True)
        display.text("b--|", 20, DISPLAY_LINE_HEIGHT * 4 - 1, True)
        display.text("C--|", 20, DISPLAY_LINE_HEIGHT * 5 - 2, True)
        display.text("d--", 20, DISPLAY_LINE_HEIGHT * 6 - 3, True)
    elif value_parm == 3:
        display.text("A-----", 20, DISPLAY_LINE_HEIGHT * 3, True)
        display.text("      +--d-->", 20, DISPLAY_LINE_HEIGHT * 4, True)
        display.text("b--c--", 20, DISPLAY_LINE_HEIGHT * 5, True)
    elif value_parm == 4:
        display.text("A--b--c--d-->", 20, DISPLAY_LINE_HEIGHT * 4, True)
    elif value_parm == 5:
        display.text("A--b--", 20, DISPLAY_LINE_HEIGHT * 3, True)
        display.text("      +-->", 20, DISPLAY_LINE_HEIGHT * 4, True)
        display.text("C--d--", 20, DISPLAY_LINE_HEIGHT * 5, True)
    elif value_parm == 6:
        display.text("A--------", 20, DISPLAY_LINE_HEIGHT * 3, True)
        display.text("         +-->", 20, DISPLAY_LINE_HEIGHT * 4, True)
        display.text("b--c--d--", 20, DISPLAY_LINE_HEIGHT * 5, True)
    elif value_parm == 7:
        display.text("   A--", 20, DISPLAY_LINE_HEIGHT * 3, True)
        display.text("b--c--+-->", 20, DISPLAY_LINE_HEIGHT * 4, True)
        display.text("   d--", 20, DISPLAY_LINE_HEIGHT * 5, True)


# GUI editor definitions
GUI_EDITOR = [
    # Algorithm
    {"items": [1],
     "func": gui_tone_edit_algorithm,
     "disp": None
    },
    # Wave Shape, Total Volume, Multi Control Magnification Frequency
    {"items": [3, 4, 5, 20, 21, 22, 37, 38, 39, 54, 55, 56],
     "func": gui_tone_edit_volumes,
     "disp": [
         ("A:", 0, DISPLAY_LINE_HEIGHT*2), ("V:", 0, DISPLAY_LINE_HEIGHT*3), ("M:", DISPLAT_QUOT_WIDTH, DISPLAY_LINE_HEIGHT*3),
         ("B:", DISPLAT_HALF_WIDTH+2, DISPLAY_LINE_HEIGHT*2), ("V:", DISPLAT_HALF_WIDTH+2, DISPLAY_LINE_HEIGHT*3), ("M:", DISPLAT_HALF_WIDTH+DISPLAT_QUOT_WIDTH+2, DISPLAY_LINE_HEIGHT*3),
         ("C:", 0, DISPLAY_LINE_HEIGHT*4+4), ("V:", 0, DISPLAY_LINE_HEIGHT*5+4), ("M:", DISPLAT_QUOT_WIDTH, DISPLAY_LINE_HEIGHT*5+4),
         ("D:", DISPLAT_HALF_WIDTH+2, DISPLAY_LINE_HEIGHT*4+4), ("V:", DISPLAT_HALF_WIDTH+2, DISPLAY_LINE_HEIGHT*5+4), ("M:", DISPLAT_HALF_WIDTH+DISPLAT_QUOT_WIDTH+2, DISPLAY_LINE_HEIGHT*5+4)
              ]
    },
    # ADSSL
    {"items": [8, 9, 10, 11, 12, 25, 26, 27, 28, 29, 42, 43, 44, 45, 46, 59, 60, 61, 62, 63],
     "func": gui_tone_edit_adssls,
     "disp": None
    }
]


# Show menu
# item_move_dir: 1=item list down, -1=item list up
# slide: Number of characters to slide the vertical line diveding the item and value regions
# str_head: True = Get the item string from head / Faluse = from tail
item_menu_display_start = 0
def show_menu(item_move_dir, slide=0, str_head=True):
    global item_menu_display_start
    global menu_main, menu_category, menu_item, menu_value
    global gui_item_menu, gui_item_menu_exit

    # Get the next menu number of menu_item in gui_items list
    def get_next_to_gui_editor(gui_items, menu_item):
        find_next = menu_item
        for i in list(range(len(gui_items))):
            if gui_items[i] == find_next:
                find_next += 1
                
        find_prev = menu_item
        for i in reversed(range(len(gui_items))):
            if gui_items[i] == find_prev:
                find_prev -= 1
                
        return (find_prev, find_next)

#    print(SYNTH_MENU)
#    print(menu_main, menu_category, menu_item, menu_value)

    # Vertical divide point
    v_divide = DISPLAY_DIVIDE - slide * 8

    # Show MAIN and CATEGORY
    main_name = SYNTH_MENU[menu_main]["name"]
    category_name = SYNTH_MENU[menu_main]["CATEGORY"][menu_category]["name"]
    if main_name == "PLAY":
        main_name = main_name + ":BANK=" + str(YMF825pico.get_databank())

    elif main_name == "TONE EDIT":
        selected = SYNTH_MENU[menu_main]["CATEGORY"][menu_category]["ITEM"][1]["selected"]
        algo = SYNTH_MENU[menu_main]["CATEGORY"][menu_category]["ITEM"][1]["VALUE"][selected]["name"]
#        print("ALGO=", menu_main, menu_category, selected, algo)
        main_name = main_name + ":" + algo

    display.fill(0)
    display.text(main_name, 0, 0, True)
    display.hline(0, DISPLAY_LINE_HEIGHT - 2, DISPLAY_WIDTH, True)
    display.text(category_name, 0, DISPLAY_LINE_HEIGHT, True)
    display.hline(0, DISPLAY_LINE_HEIGHT * 2 - 2, DISPLAY_WIDTH, True)
    
    # Use GUI Editor
    if menu_main == MAIN_MENU_TONE_EDIT:
        for gui in GUI_EDITOR:
#            print("GUI CHECK:", menu_item, gui)
            if menu_item in gui["items"]:
                if gui_item_menu_exit is None:
                    gui_item_menu_exit = get_next_to_gui_editor(gui["items"], menu_item)
#                    print("NEXT ITEM MENU=", gui_item_menu_exit)

                gui["func"](gui)
                display.show()
                return

    # Text Editor Menu
    gui_item_menu = None
    gui_item_menu_exit = None

    # Show ITEM and VALUE
    display.vline(v_divide, DISPLAY_LINE_HEIGHT * 2 - 2, DISPLAY_HEIGHT - (DISPLAY_LINE_HEIGHT * 2 - 2), True)
    items = len(SYNTH_MENU[menu_main]["CATEGORY"][menu_category]["ITEM"])
    if menu_item < DISPLAY_MENU_LINES:
        menu_s = 0
    elif menu_item >= items - DISPLAY_MENU_LINES:
        menu_s = items - DISPLAY_MENU_LINES
    elif item_move_dir == 1 and menu_item >= item_menu_display_start + DISPLAY_MENU_LINES:
        menu_s = item_menu_display_start + 1
    elif item_move_dir == -1 and menu_item < item_menu_display_start:
        menu_s = item_menu_display_start - 1
    else:
        menu_s = item_menu_display_start

#    print("MOVE DIR, s, e=", item_move_dir, menu_s, menu_s + DISPLAY_MENU_LINES)
    item_menu_display_start = menu_s
    y = DISPLAY_LINE_HEIGHT * 2
    for i in list(range(menu_s, min(items, menu_s + DISPLAY_MENU_LINES))):
        # Show ITEM
        item_name = SYNTH_MENU[menu_main]["CATEGORY"][menu_category]["ITEM"][i]["name"]
        display.text(item_name if slide == 0 else item_name[0:10-slide] if str_head else item_name[slide-10:], 0, y, True)
        
        # Show the current editing VALUE
        if i == menu_item:
#            print("main, category, item, value=", menu_main, menu_category, i, menu_value)
            value_name = SYNTH_MENU[menu_main]["CATEGORY"][menu_category]["ITEM"][i]["VALUE"][menu_value]["name"]
            display.hline(0, y + DISPLAY_LINE_HEIGHT - 2, DISPLAY_WIDTH, True)
        # Show the selected VALUE
        else:
            selected = int(SYNTH_MENU[menu_main]["CATEGORY"][menu_category]["ITEM"][i]["selected"])
#            print("MENU:", menu_main, menu_category, i, selected)
            value_name = SYNTH_MENU[menu_main]["CATEGORY"][menu_category]["ITEM"][i]["VALUE"][selected]["name"]

#        print("SHOW=", value_name)
        display.text(value_name, v_divide + 2, y, True)
        y += DISPLAY_LINE_HEIGHT

    display.show()


# Clear list memory for SYNTH_MENU
def clear_menu_memory(prev, clear_category, clear_item, clear_value):
    global menu_main, menu_category, menu_item, menu_value

    if prev < 0:
        return

    target_main = menu_main
    target_category = menu_category
    target_item = menu_item

    if clear_category:
        target_main = prev
        menu_category = 0
        menu_item = 0
        menu_value = 0

    elif clear_item:
        target_category = prev
        menu_item = 0
        menu_value = 0

    elif clear_value:
        target_item = prev
        menu_value = 0
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

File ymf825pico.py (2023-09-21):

# -*- coding: utf-8 -*-
##################################################################################
# YMF825 synthesizer with Raspberry Pi PICO Class.
#
# Hardware Information:
#   YMF825 bottom view
#     1 2 3 4 5 6 7 8 9
#    -+-+-+-+-+-+-+-+-+-
#   | S M M C G V R     |
#   | S O I L N C S     |
#   |   S S K D C T     |
#   |   I O             |
#   |             Audio Jack
#    ---------------+---
#                   |
#                    ---Amp
#
#   PICO GPIO(pin)      YMF825 name(pin)    LED(n/a)
#     5V          (40)    VCC        (6)
#     GND         (38)    GND        (5)
#     SPI1 MOSI 19(25)    SPI MOSI   (2)
#     SPI1 MISO 16(21)    SPI MISO   (3)
#     SPI1 CLK  18( 24)    SPI CLK    (4)
#     SPI1 CS   17(22)    SS         (1)
#     RESET     22(29)    RESET      (7)
#n/a  LED       28(34)                      Anode---1K--->|---Cathode---GND
#
# Synthesizer Structure
#             ---PORTION0:VOICEa..b---TONEp---
#            |                                |
#            |---PORTION1:VOICEc..d---TONEq---|
#   TIMBREx--|                                |---SOUND--->YMF825
#            |---PORTION2:VOICEe..f---TONEr---|
#            |                                |
#             ---PORTION3:VOICEg..h---TONEs---
#
#     This synthesizer has TIMBRES timbres.
#     Each timbre has 4 portions.
#     Each portion is able to have some voices (from 0 to 16).
#     A voice is one of voice chanel in YMF825.  YMF825 has voices from 0 to 15. 
#     Each voice use a tone data.  Tone is a set of YMF825 sound parameters.
#
# Copyright (c) by Shunsuke Ohira
#   00.600 2022/05/09: For Pi400 (original)
#   00.100 2023/08/05: For PICO W
#   01.000 2023/08/31: MIDI Keyboard available.
#   01.001 2023/09/04: Databank available
#   01.002 2023/09/19: Reduce global variable memory
#   01.300 2023/09/19: Tones in the timbre can be selected from the other databank
#   01.500 2023/09/21: MIDI channel can be assigned to each timbre portion
##################################################################################

from machine import Pin, SPI
import time
import json
import re
#from decimal import Decimal
import math


## YMF825 hardware control class for Raspberry Pi PICO W ##
class ymf825pico_class:

    # Initializer
    def __init__( self, file_tone_name = "YMF825ToneName.txt", file_tone_param = "YMF825ToneParm.txt", file_timbre_name = "YMF825TimbreName.txt", file_timbre_param = "YMF825TimbreParm.txt", file_equalizer_name = "YMF825EQName.txt", file_equalizer_param = "YMF825EQParm.txt", file_encode = "utf-8" ):
        # PICO GPIO and pin no.
        self.SPI_CH = 0
        self.SPIPORT_MOSI = 19    # pin25
        self.SPIPORT_MISO = 16    # pin21
        self.SPIPORT_CLK  = 18    # pin24
        self.SPIPORT_CE   = 17    # pin22
        self.YMF825_RESET = 22    # pin29
        self.GPIO_LED     = 28    # pin34    # N/A

        # SPI mode0
        self.SPI_MAX_SPEED_HZ = 1000000
        self.spi_cs = Pin(self.SPIPORT_CE, Pin.OUT)
        self.spi = SPI(self.SPI_CH, sck=Pin(self.SPIPORT_CLK), mosi=Pin(self.SPIPORT_MOSI), miso=Pin(self.SPIPORT_MISO), baudrate=self.SPI_MAX_SPEED_HZ, firstbit=SPI.MSB, polarity=0, phase=0)

        # YMF825 RESET pin
        self.YMF825_reset = Pin(self.YMF825_RESET, Pin.OUT)

        # LED (CURRENTLY NOT AVAILABLE)
        self.led_indicator = Pin(self.GPIO_LED, Pin.OUT)

        #Tone parameter [address(1byte)|data(35byte)].
        self.sound_param = bytearray(36)

        # Note number and Note name
        self.note_str = ["C_","C_#","D_","D_#","E_","F_","F_#","G_","G_#","A_","A_#","B_"]
        
        #Tone data HI.
        self.notenum_hi = (0x10,0x10,0x10,0x10,0x10,0x10,0x10,0x10,0x10,0x10,0x10,0x10,0x10,0x10,0x18,0x18,0x18,0x18,0x18,0x20,0x20,0x20,0x20,0x28,0x11,0x11,0x19,0x19,0x19,0x19,0x19,0x21,0x21,0x21,0x21,0x29,0x12,0x12,0x1A,0x1A,0x1A,0x1A,0x1A,0x22,0x22,0x22,0x22,0x2A,0x13,0x13,0x1B,0x1B,0x1B,0x1B,0x1B,0x23,0x23,0x23,0x23,0x2B,0x14,0x14,0x1C,0x1C,0x1C,0x1C,0x1C,0x24,0x24,0x24,0x24,0x2C,0x15,0x15,0x1D,0x1D,0x1D,0x1D,0x1D,0x25,0x25,0x25,0x25,0x2D,0x16,0x16,0x1E,0x1E,0x1E,0x1E,0x1E,0x26,0x26,0x26,0x26,0x2E,0x17,0x17,0x1F,0x1F,0x1F,0x1F,0x1F,0x27,0x27,0x27,0x27,0x2F,0x10,0x10,0x18,0x18,0x18,0x18,0x18,0x20,0x20,0x20,0x20,0x28,0x11,0x11,0x19,0x19,0x19,0x19,0x10,0x1E)
        #Tone data LO.
        self.notenum_lo = (0x65,0x65,0x65,0x65,0x65,0x65,0x65,0x65,0x65,0x65,0x65,0x65,0x65,0x7A,0x11,0x29,0x42,0x5D,0x79,0x17,0x37,0x59,0x7D,0x22,0x65,0x7A,0x11,0x29,0x42,0x5D,0x79,0x17,0x37,0x59,0x7D,0x22,0x65,0x7A,0x11,0x29,0x42,0x5D,0x79,0x17,0x37,0x59,0x7D,0x22,0x65,0x7A,0x11,0x29,0x42,0x5D,0x79,0x17,0x37,0x59,0x7D,0x22,0x65,0x7A,0x11,0x29,0x42,0x5D,0x79,0x17,0x37,0x59,0x7D,0x22,0x65,0x7A,0x11,0x29,0x42,0x5D,0x79,0x17,0x37,0x59,0x7D,0x22,0x65,0x7A,0x11,0x29,0x42,0x5D,0x79,0x17,0x37,0x59,0x7D,0x22,0x65,0x7A,0x11,0x29,0x42,0x5D,0x79,0x17,0x37,0x59,0x7D,0x22,0x65,0x7A,0x11,0x29,0x42,0x5D,0x79,0x17,0x37,0x59,0x7D,0x22,0x65,0x7A,0x11,0x29,0x42,0x5D,0x65,0x5D)

        #Tone parameter byte order and how to make a byte data
        self.synth_data_map = {
            ##COMMON
            # [ 2]: NOP 000000 | Basic Octave 11
            "Basic Oct":                           {"BYTE":  2, "SELF_MASK": 0x03, "SHFT_LEFT": 0, "DATA_MASK": 0x00},

            # [ 3]:LFO 11 | NOP 000 | Algorithm 111
            "LFO":                                    {"BYTE":  3, "SELF_MASK": 0x03, "SHFT_LEFT": 6, "DATA_MASK": 0x07},
            "Algorithm":                              {"BYTE":  3, "SELF_MASK": 0x07, "SHFT_LEFT": 0, "DATA_MASK": 0xf8},

            ##OP1
            # [ 4]: OP1:Sustain Rate 1111 | Ignore Key Off 0 | Key Scale Sensitivity 111
            "Sus R1":                          {"BYTE":  4, "SELF_MASK": 0x0f, "SHFT_LEFT": 4, "DATA_MASK": 0x0f},
            "Ign Key Off1":                        {"BYTE":  4, "SELF_MASK": 0x01, "SHFT_LEFT": 3, "DATA_MASK": 0xf7},
            "KeySc Sens1":                 {"BYTE":  4, "SELF_MASK": 0x07, "SHFT_LEFT": 0, "DATA_MASK": 0xf8},

            # [ 5]: OP1:Release Rate 1111 | Decay Rate 0000
            "Release R1":                          {"BYTE":  5, "SELF_MASK": 0x0f, "SHFT_LEFT": 4, "DATA_MASK": 0x0f},
            "Decay R1":                            {"BYTE":  5, "SELF_MASK": 0x0f, "SHFT_LEFT": 0, "DATA_MASK": 0xf0},

            # [ 6]: OP1:Attack Rate 1111 | Sustain Level 0000
            "Attack R1":                           {"BYTE":  6, "SELF_MASK": 0x0f, "SHFT_LEFT": 4, "DATA_MASK": 0x0f},
            "Sus Level1":                         {"BYTE":  6, "SELF_MASK": 0x0f, "SHFT_LEFT": 0, "DATA_MASK": 0xf0},

            # [ 7]: OP1:Total Operator Level 111111 | Key Scale Level Sensivitiy 00
            "Operator Lv1":                  {"BYTE":  7, "SELF_MASK": 0x3f, "SHFT_LEFT": 2, "DATA_MASK": 0x03},
            "KSL Sens1":            {"BYTE":  7, "SELF_MASK": 0x03, "SHFT_LEFT": 0, "DATA_MASK": 0xfc},
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

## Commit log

2023-08-30 YMF825 FM synthesizer controlled with Raspberry Pi PICO.
    [YMF825pico.fzz]
2023-08-31 - BUGs were fixed. - MIDI channel for note on/off is supported. MIDI channel correspond to the timbre of YMF825pico (Timbre = MIDI CH % 4) - MIDI Pitch+/Pitch- events change the base timbre number (d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
    [ymf825pico_synth_main.py]
2023-09-05 # Updates - A timbre volume value controls the timbre's master volume.
    The value range is 0..31, it is mapped to 0% to 100% master volume value.
    - Bugs fixed.
    [ymf825pico.py, ymf825pico_synth_main.py]
2023-09-21 - A MIDI channel is assigned to each timbre portion. - Calculate a biquad filter parameters with both a cut off frequency and a Q value in the equalizer editor.
2023-09-21 Remove all print functions for debug to reduce memory size.
2023-09-23 Improve UART data receive not to lose MIDI message. Manual updated.
